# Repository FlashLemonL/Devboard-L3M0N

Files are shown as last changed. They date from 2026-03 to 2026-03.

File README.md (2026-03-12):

# Devboard-L3M0N
My attempt at making a devboard using the tutorial for when i want to start making IoT projects.

# 3D Model of PCB
Front 
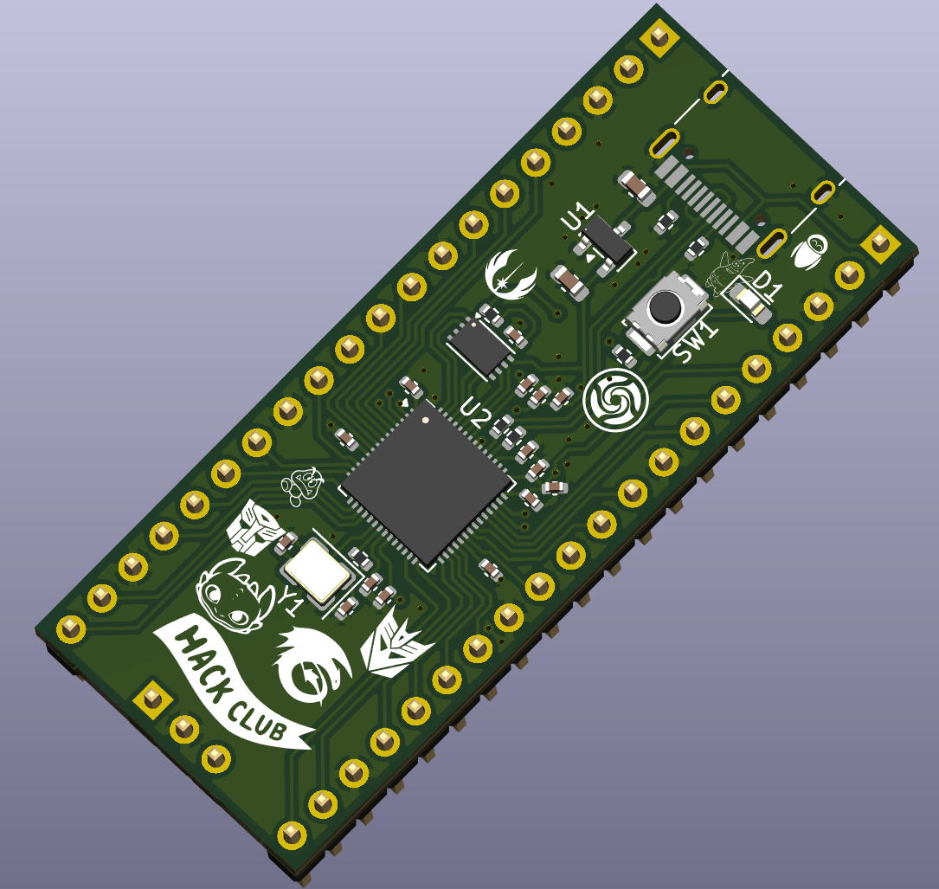
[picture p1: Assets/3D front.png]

Back
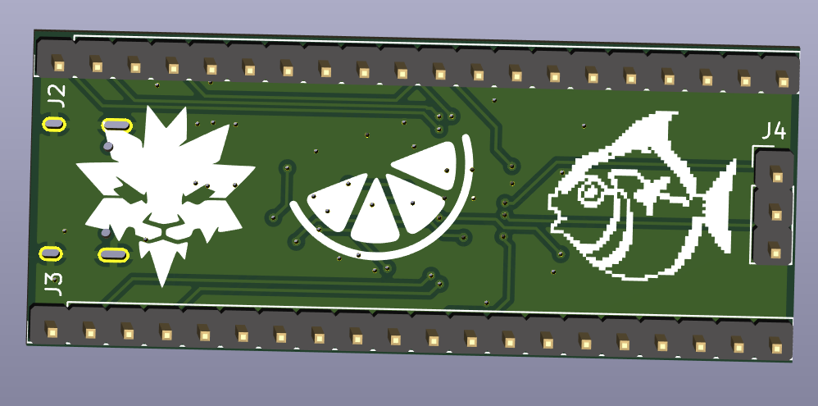
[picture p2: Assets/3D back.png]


# BOM
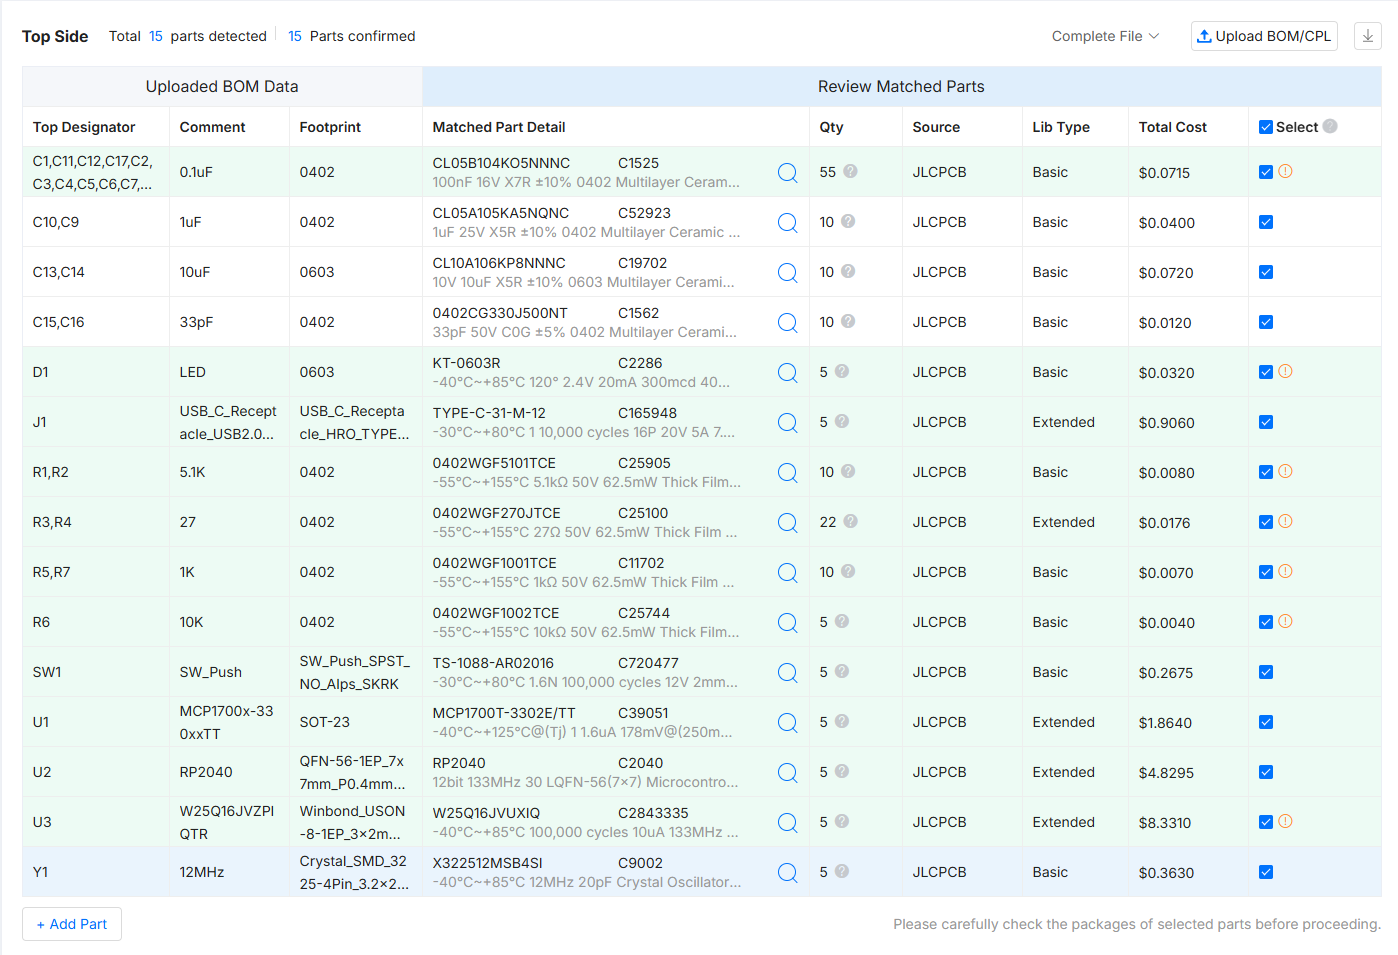
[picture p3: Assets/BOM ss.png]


# Parts Position
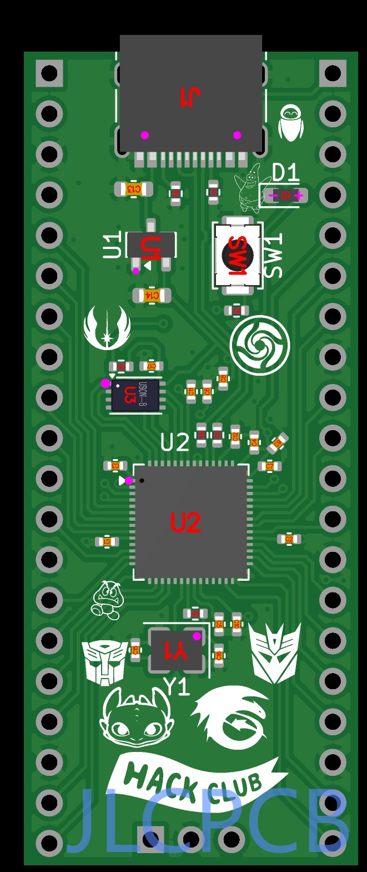
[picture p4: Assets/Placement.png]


# PCB
Schematic            |  PCB         |
:-------------------------:|:-------------------------:|
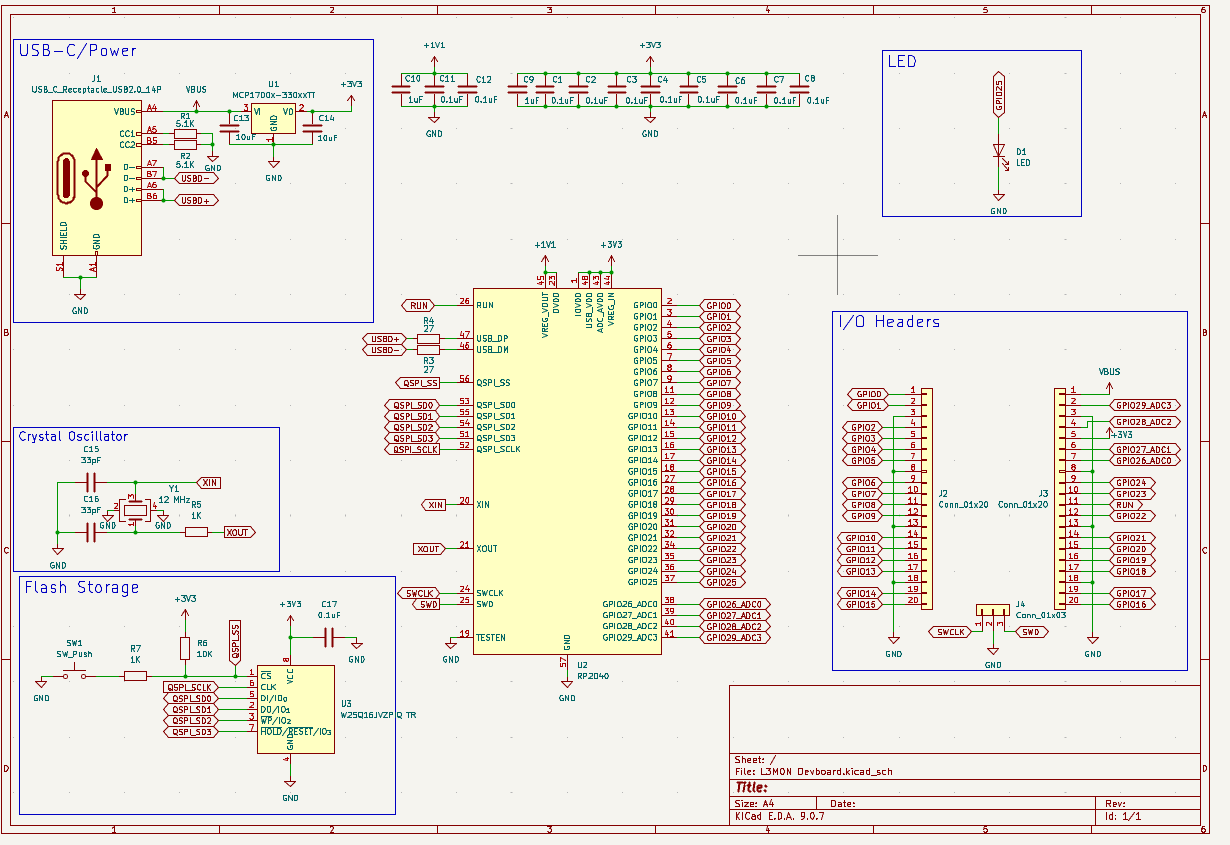
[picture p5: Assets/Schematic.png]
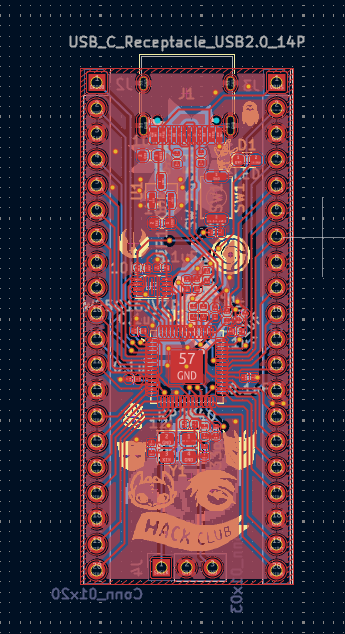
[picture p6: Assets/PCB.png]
    |    |

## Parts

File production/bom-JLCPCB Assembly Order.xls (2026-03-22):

JLCPCB BOM Tool - BOM Matching
BOM name：bom-JLCPCB Assembly Order.xlsx |  |  | Download Time：2026-03-22 16:55:20 |  |  |  | * Our matching results are updated in real-time, but stock and prices may change. If it's been over 24 hours, please re-match before placing your order.
PCB Assembled Qty：5 |  |  | Est. Total Price：16.8251
Your BOM |  |  |  |  | Matched Parts |  |  |  |  |  |  | Order Information
Top Designator | Bottom Designator | Comment | Footprint | JLCPCB Part # | Matches | Part # | Manufacturer | Footprint | Description | Category | Warning | JLCPCB Part # | Product link | Lib Type | Qty | Source | Total Price ($)
C1,C11,C12,C17,C2,C3,C4,C5,C6,C7,C8 |  | 0.1uF | 0402 |  | Select by Customer | CL05B104KO5NNNC | Samsung Electro-Mechanics | 0402 | 100nF 16V X7R ±10% 0402 Multilayer Ceramic Capacitors MLCC - SMD/SMT ROHS | Multilayer Ceramic Capacitors MLCC - SMD/SMT | 1.The comment (CL05B104KO5NNNC) of this part does not match the one (0.1uF) provided in your BOM. Please confirm; | C1525 | https://jlcpcb.com/partdetail/1877-CL05B104KO5NNNC/C1525 | Basic | 55 | 55 JLCPCB | 0.0715
C10,C9 |  | 1uF | 0402 |  | Select by System | CL05A105KA5NQNC | Samsung Electro-Mechanics | 0402 | 1uF 25V X5R ±10% 0402 Multilayer Ceramic Capacitors MLCC - SMD/SMT ROHS | Multilayer Ceramic Capacitors MLCC - SMD/SMT |  | C52923 | https://jlcpcb.com/partdetail/53938-CL05A105KA5NQNC/C52923 | Basic | 10 | 10 JLCPCB | 0.04
C13,C14 |  | 10uF | 0603 |  | Select by System | CL10A106KP8NNNC | Samsung Electro-Mechanics | 0603 | 10V 10uF X5R ±10% 0603 Multilayer Ceramic Capacitors MLCC - SMD/SMT ROHS | Multilayer Ceramic Capacitors MLCC - SMD/SMT |  | C19702 | https://jlcpcb.com/partdetail/20411-CL10A106KP8NNNC/C19702 | Basic | 10 | 10 JLCPCB | 0.072
C15,C16 |  | 33pF | 0402 |  | Select by System | 0402CG330J500NT | FH (Guangdong Fenghua Advanced Tech) | 0402 | 33pF 50V C0G ±5% 0402 Multilayer Ceramic Capacitors MLCC - SMD/SMT ROHS | Multilayer Ceramic Capacitors MLCC - SMD/SMT |  | C1562 | https://jlcpcb.com/partdetail/1914-0402CG330J500NT/C1562 | Basic | 10 | 10 JLCPCB | 0.012
D1 |  | LED | 0603 |  | Select by Customer | KT-0603R | Hubei KENTO Elec | 0603 | -40℃~+85℃ 120° 2.4V 20mA 300mcd 40mW 615nm~630nm 645nm Discrete Diode Red Water Clear 0603 LED Indication - Discrete ROHS | LED Indication - Discrete | 1.The comment (KT-0603R) of this part does not match the one (LED) provided in your BOM. Please confirm; | C2286 | https://jlcpcb.com/partdetail/Hubei_KENTOElec-KT0603R/C2286 | Basic | 5 | 5 JLCPCB | 0.032
J1 |  | USB_C_Receptacle_USB2.0_14P | USB_C_Receptacle_HRO_TYPE-C-31-M-12 |  | Select by Customer | TYPE-C-31-M-12 | Korean Hroparts Elec | SMD | -30℃~+80℃ 1 10,000 cycles 16P 20V 5A 7.35mm Female Surface Mount, Right Angle Type-C SMD USB Connectors ROHS | USB Connectors |  | C165948 | https://jlcpcb.com/partdetail/Korean_HropartsElec-TYPE_C_31_M12/C165948 | Extended | 5 | 5 JLCPCB | 0.906
R1,R2 |  | 5.1K | 0402 |  | Select by Customer | 0402WGF5101TCE | UNI-ROYAL(Uniroyal Elec) | 0402 | -55℃~+155℃ 5.1kΩ 50V 62.5mW Thick Film Resistor ±1% ±100ppm/℃ 0402 Chip Resistor - Surface Mount ROHS | Chip Resistor - Surface Mount | 1.The comment (0402WGF5101TCE) of this part does not match the one (5.1K) provided in your BOM. Please confirm; | C25905 | https://jlcpcb.com/partdetail/26648-0402WGF5101TCE/C25905 | Basic | 10 | 10 JLCPCB | 0.008
R3,R4 |  | 27 | 0402 |  | Select by Customer | 0402WGF270JTCE | UNI-ROYAL(Uniroyal Elec) | 0402 | -55℃~+155℃ 27Ω 50V 62.5mW Thick Film Resistor ±1% ±100ppm/℃ 0402 Chip Resistor - Surface Mount ROHS | Chip Resistor - Surface Mount | 1.The comment (0402WGF270JTCE) of this part does not match the one (27) provided in your BOM. Please confirm; | C25100 | https://jlcpcb.com/partdetail/25843-0402WGF270JTCE/C25100 | Extended | 22 | 22 JLCPCB | 0.0176
R5,R7 |  | 1K | 0402 |  | Select by Customer | 0402WGF1001TCE | UNI-ROYAL(Uniroyal Elec) | 0402 | -55℃~+155℃ 1kΩ 50V 62.5mW Thick Film Resistor ±1% ±100ppm/℃ 0402 Chip Resistor - Surface Mount ROHS | Chip Resistor - Surface Mount | 1.The comment (0402WGF1001TCE) of this part does not match the one (1K) provided in your BOM. Please confirm; | C11702 | https://jlcpcb.com/partdetail/12256-0402WGF1001TCE/C11702 | Basic | 10 | 10 JLCPCB | 0.007
R6 |  | 10K | 0402 |  | Select by Customer | 0402WGF1002TCE | UNI-ROYAL(Uniroyal Elec) | 0402 | -55℃~+155℃ 10kΩ 50V 62.5mW Thick Film Resistor ±1% ±100ppm/℃ 0402 Chip Resistor - Surface Mount ROHS | Chip Resistor - Surface Mount | 1.The comment (0402WGF1002TCE) of this part does not match the one (10K) provided in your BOM. Please confirm; | C25744 | https://jlcpcb.com/partdetail/26487-0402WGF1002TCE/C25744 | Basic | 5 | 5 JLCPCB | 0.004
SW1 |  | SW_Push | SW_Push_SPST_NO_Alps_SKRK |  | Select by Customer | TS-1088-AR02016 | XUNPU | SMD,4x3mm | -30℃~+80℃ 1.6N 100,000 cycles 12V 2mm 3mm 4mm 50mA Black Round Button SMD(SMT) Tab SPST Surface Mount,Vertical Without Bracket SMD,4x3mm Tactile Switches ROHS | Tactile Switches |  | C720477 | https://jlcpcb.com/partdetail/XUNPU-TS_1088AR02016/C720477 | Basic | 5 | 5 JLCPCB | 0.2675
U1 |  | MCP1700x-330xxTT | SOT-23 |  | Select by Customer | MCP1700T-3302E/TT | Microchip Tech | SOT-23 | -40℃~+125℃@(Tj) 1 1.6uA 178mV@(250mA) 250mA 3.3V 44dB@(100Hz) 6V Fixed Over Temperature Protection、Short Circuit Protection Positive SOT-23 Voltage Regulators - Linear, Low Drop Out (LDO) Regulators ROHS | Voltage Regulators - Linear, Low Drop Out (LDO) Regulators |  | C39051 | https://jlcpcb.com/partdetail/MicrochipTech-MCP1700T_3302ETT/C39051 | Extended | 5 | 5 JLCPCB | 1.864
U2 |  | RP2040 | QFN-56-1EP_7x7mm_P0.4mm_EP3.2x3.2mm |  | Select by Customer | RP2040 | Raspberry Pi | LQFN-56(7x7) | 12bit 133MHz 30 LQFN-56(7x7) Microcontrollers (MCU/MPU/SOC) ROHS | Microcontrollers (MCU/MPU/SOC) |  | C2040 | https://jlcpcb.com/partdetail/RaspberryPi-RP2040/C2040 | Extended | 5 | 5 JLCPCB | 4.8295
U3 |  | W25Q16JVZPIQTR | Winbond_USON-8-1EP_3x2mm_P0.5mm_EP0.2x1.6mm |  | Select by Customer | W25Q16JVUXIQ | Winbond Elec | USON-8-EP(2x3) | -40℃~+85℃ 100,000 cycles 10uA 133MHz 16Mbit 2.7V~3.6V 20 Years 3ms SPI USON-8-EP(2x3) NOR FLASH ROHS | NOR FLASH | 1.The comment (W25Q16JVUXIQ) of this part does not match the one (W25Q16JVZPIQTR) provided in your BOM. Please confirm; | C2843335 | https://jlcpcb.com/partdetail/WinbondElec-W25Q16JVUXIQ/C2843335 | Extended | 5 | 5 JLCPCB | 8.331
Y1 |  | 12MHz | Crystal_SMD_3225-4Pin_3.2x2.5mm |  | Select by Customer | X322512MSB4SI | YXC Crystal Oscillators | SMD3225-4P | -40℃~+85℃ 12MHz 20pF Crystal Oscillator ±10ppm ±20ppm SMD3225-4P Crystals ROHS | Crystals |  | C9002 | https://jlcpcb.com/partdetail/YXC_CrystalOscillators-X322512MSB4SI/C9002 | Basic | 5 | 5 JLCPCB | 0.363

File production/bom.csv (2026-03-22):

Designator | Footprint | Quantity | Value | LCSC Part #
C1, C11, C12, C17, C2, C3, C4, C5, C6, C7, C8 | 0402 | 11 | 0.1uF
C10, C9 | 0402 | 2 | 1uF
C13, C14 | 0603 | 2 | 10uF
C15, C16 | 0402 | 2 | 33pF
D1 | 0603 | 1 | LED
J1 | USB_C_Receptacle_HRO_TYPE-C-31-M-12 | 1 | USB_C_Receptacle_USB2.0_14P
J2, J3 | PinHeader_1x20_P2.54mm_Vertical | 2 | Conn_01x20
J4 | PinHeader_1x03_P2.54mm_Vertical | 1 | Conn_01x03
R1, R2 | 0402 | 2 | 5.1K
R3, R4 | 0402 | 2 | 27
R5, R7 | 0402 | 2 | 1K
R6 | 0402 | 1 | 10K
SW1 | SW_Push_SPST_NO_Alps_SKRK | 1 | SW_Push
U1 | SOT-23 | 1 | MCP1700x-330xxTT
U2 | QFN-56-1EP_7x7mm_P0.4mm_EP3.2x3.2mm | 1 | RP2040
U3 | Winbond_USON-8-1EP_3x2mm_P0.5mm_EP0.2x1.6mm | 1 | W25Q16JVZPIQ TR
Y1 | Crystal_SMD_3225-4Pin_3.2x2.5mm | 1 | 12 MHz

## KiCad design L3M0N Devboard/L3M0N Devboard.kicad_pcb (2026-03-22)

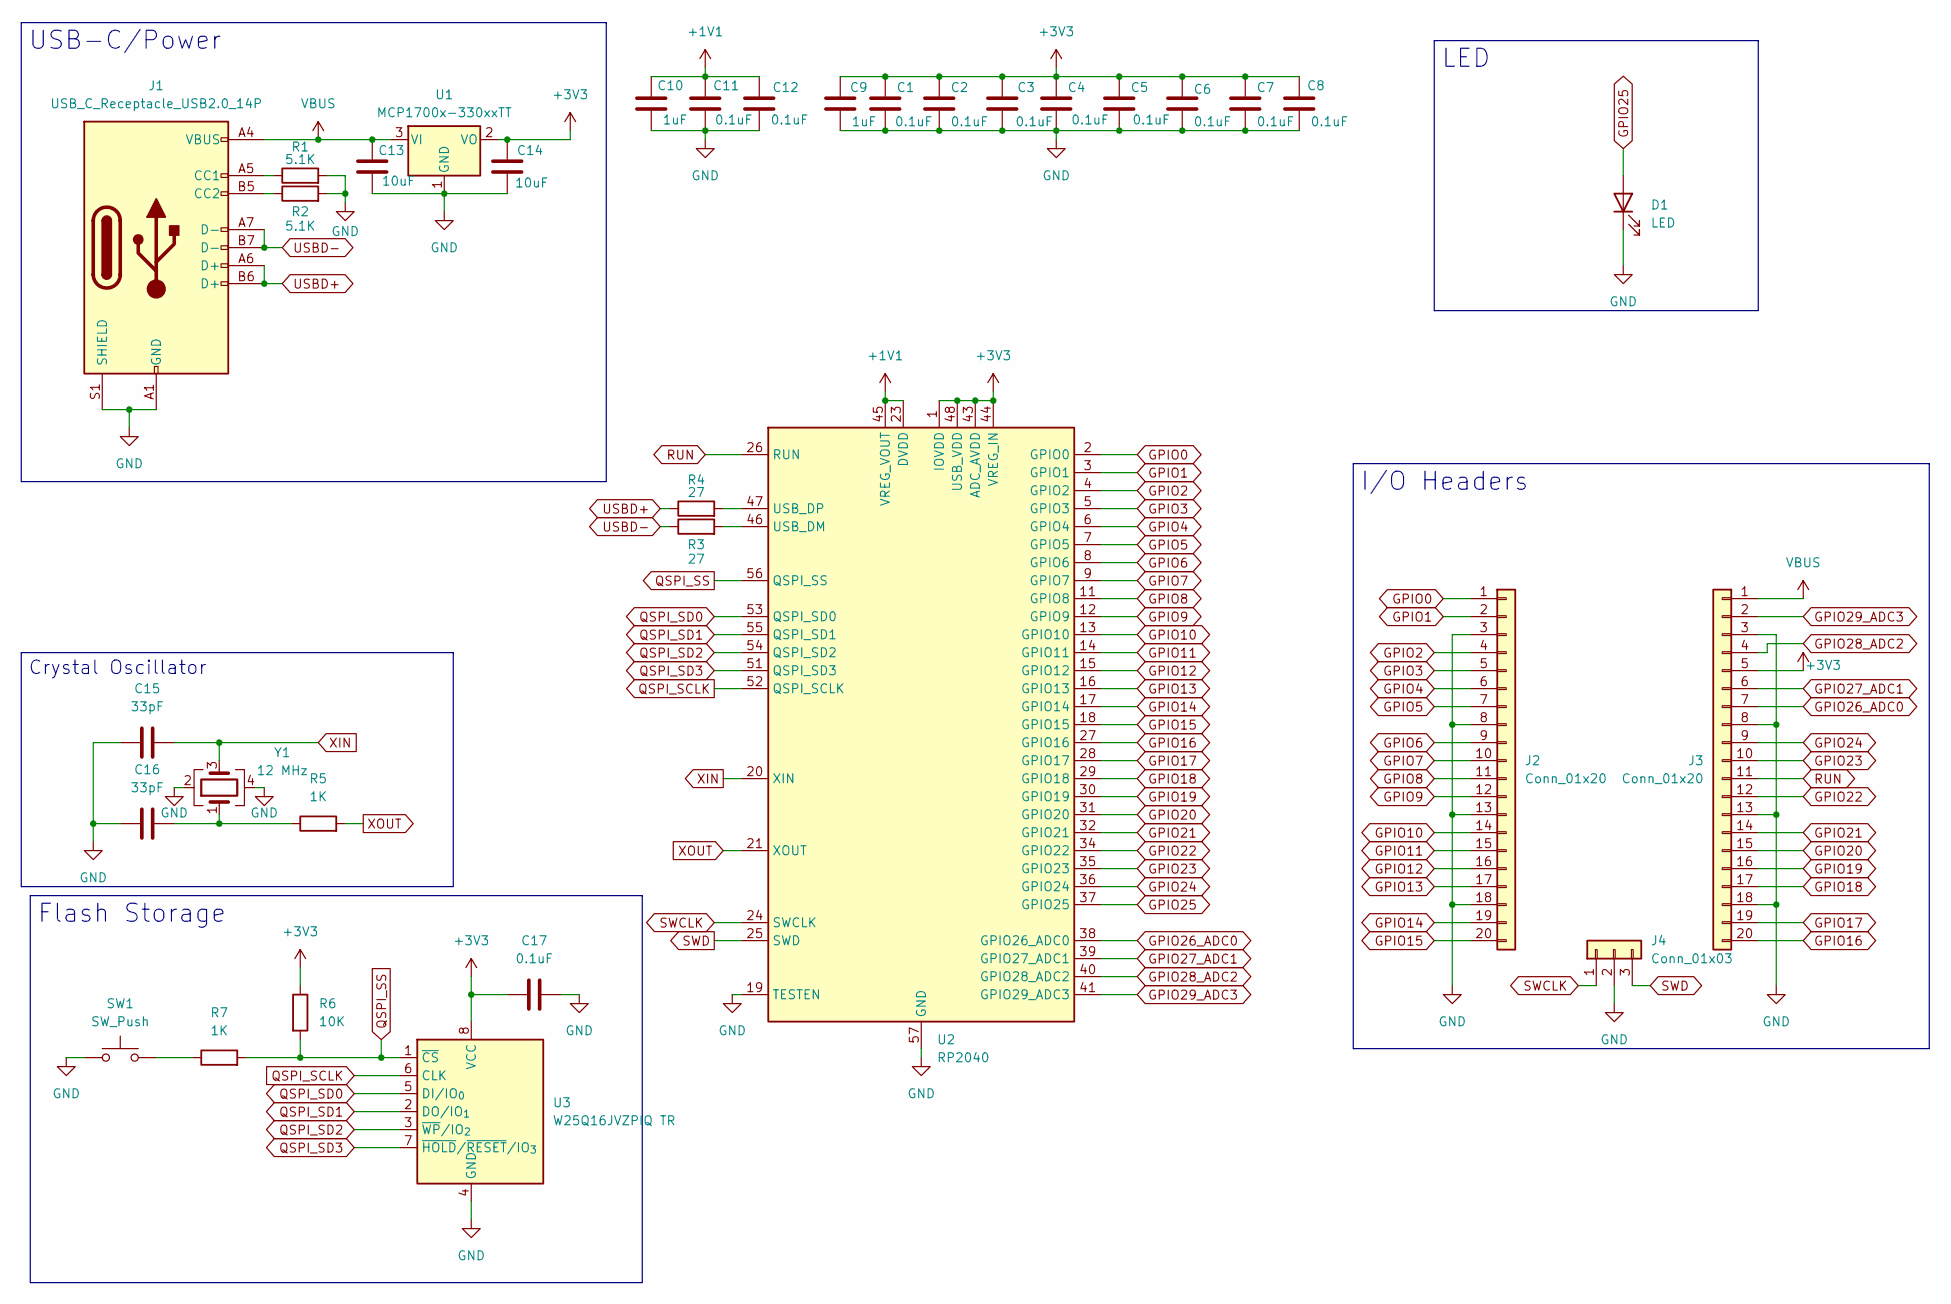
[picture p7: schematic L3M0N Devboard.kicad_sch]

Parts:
C1, C2, C3, C4, C5, C6, C7, C8, C11, C12, C17: 0.1uF; C_0402_1005Metric
C9, C10: 1uF; C_0402_1005Metric
C13, C14: 10uF; C_0603_1608Metric
C15, C16: 33pF; C_0402_1005Metric
D1: LED; LED_0603_1608Metric_Pad1.05x0.95mm_HandSolder
J1: USB_C_Receptacle_USB2.0_14P; USB_C_Receptacle_HRO_TYPE-C-31-M-12
J2, J3: Conn_01x20; PinHeader_1x20_P2.54mm_Vertical
J4: Conn_01x03; PinHeader_1x03_P2.54mm_Vertical
R1, R2: 5.1K; R_0402_1005Metric
R3, R4: 27; R_0402_1005Metric
R5, R7: 1K; R_0402_1005Metric
R6: 10K; R_0402_1005Metric
SW1: SW_Push; SW_Push_SPST_NO_Alps_SKRK
U1: MCP1700x-330xxTT; SOT-23
U2: RP2040; QFN-56-1EP_7x7mm_P0.4mm_EP3.2x3.2mm
U3: W25Q16JVZPIQ TR; Winbond_USON-8-1EP_3x2mm_P0.5mm_EP0.2x1.6mm
Y1: 12 MHz; Crystal_SMD_3225-4Pin_3.2x2.5mm

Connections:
+1V1: C10.1, C11.1, C12.1, U2.23 (DVDD), U2.45 (VREG_VOUT), U2.50 (DVDD)
+3V3: C1.1, C2.1, C3.1, C4.1, C5.1, C6.1, C7.1, C8.1, C9.1, C14.1, C17.1, J3.5, R6.1, U1.2 (VO), U2.1 (IOVDD), U2.10 (IOVDD), U2.22 (IOVDD), U2.33 (IOVDD), U2.42 (IOVDD), U2.43 (ADC_AVDD), U2.44 (VREG_IN), U2.48 (USB_VDD), U2.49 (IOVDD), U3.8 (VCC)
GND: C1.2, C2.2, C3.2, C4.2, C5.2, C6.2, C7.2, C8.2, C9.2, C10.2, C11.2, C12.2, C13.2, C14.2, C15.2, C16.1, C17.2, D1.1 (K), J1.A1 (GND), J1.A12 (GND), J1.B1 (GND), J1.B12 (GND), J1.S1 (SHIELD), J2.3, J2.8, J2.13, J2.18, J3.3, J3.8, J3.13, J3.18, J4.2, R1.2, R2.2, SW1.1, U1.1 (GND), U2.19 (TESTEN), U2.57 (GND), U3.4 (GND), Y1.2, Y1.4
GPIO0: J2.1, U2.2 (GPIO0)
GPIO1: J2.2, U2.3 (GPIO1)
GPIO2: J2.4, U2.4 (GPIO2)
GPIO3: J2.5, U2.5 (GPIO3)
GPIO4: J2.6, U2.6 (GPIO4)
GPIO5: J2.7, U2.7 (GPIO5)
GPIO6: J2.9, U2.8 (GPIO6)
GPIO7: J2.10, U2.9 (GPIO7)
GPIO8: J2.11, U2.11 (GPIO8)
GPIO9: J2.12, U2.12 (GPIO9)
GPIO10: J2.14, U2.13 (GPIO10)
GPIO11: J2.15, U2.14 (GPIO11)
GPIO12: J2.16, U2.15 (GPIO12)
GPIO13: J2.17, U2.16 (GPIO13)
GPIO14: J2.19, U2.17 (GPIO14)
GPIO15: J2.20, U2.18 (GPIO15)
GPIO16: J3.20, U2.27 (GPIO16)
GPIO17: J3.19, U2.28 (GPIO17)
GPIO18: J3.17, U2.29 (GPIO18)
GPIO19: J3.16, U2.30 (GPIO19)
GPIO20: J3.15, U2.31 (GPIO20)
GPIO21: J3.14, U2.32 (GPIO21)
GPIO22: J3.12, U2.34 (GPIO22)
GPIO23: J3.10, U2.35 (GPIO23)
GPIO24: J3.9, U2.36 (GPIO24)
GPIO25: D1.2 (A), U2.37 (GPIO25)
GPIO26_ADC0: J3.7, U2.38 (GPIO26_ADC0)
GPIO27_ADC1: J3.6, U2.39 (GPIO27_ADC1)
GPIO28_ADC2: J3.4, U2.40 (GPIO28_ADC2)
GPIO29_ADC3: J3.2, U2.41 (GPIO29_ADC3)
unnamed: C16.2, R5.1, Y1.1
unnamed: J1.A5 (CC1), R1.1
unnamed: J1.B5 (CC2), R2.1
unnamed: R7.1, SW1.2
unnamed: R3.2, U2.46 (USB_DM)
unnamed: R4.2, U2.47 (USB_DP)
QSPI_SCLK: U2.52 (QSPI_SCLK), U3.6 (CLK)
QSPI_SD0: U2.53 (QSPI_SD0), U3.5 (DI/IO_{0})
QSPI_SD1: U2.55 (QSPI_SD1), U3.2 (DO/IO_{1})
QSPI_SD2: U2.54 (QSPI_SD2), U3.3 (~WP/IO_{2})
QSPI_SD3: U2.51 (QSPI_SD3), U3.7 (~HOLD/~RESET/IO_{3})
QSPI_SS: R6.2, R7.2, U2.56 (QSPI_SS), U3.1 (~CS)
RUN: J3.11, U2.26 (RUN)
SWCLK: J4.1, U2.24 (SWCLK)
SWD: J4.3, U2.25 (SWD)
USBD+: J1.A6 (D+), J1.B6 (D+), R4.1
USBD-: J1.A7 (D-), J1.B7 (D-), R3.1
VBUS: C13.1, J1.A4 (VBUS), J1.A9 (VBUS), J1.B4 (VBUS), J1.B9 (VBUS), J3.1, U1.3 (VI)
XIN: C15.1, U2.20 (XIN), Y1.3
XOUT: R5.2, U2.21 (XOUT)

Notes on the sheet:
Flash Storage
USB-C/Power
I/O Headers
Crystal Oscillator
LED

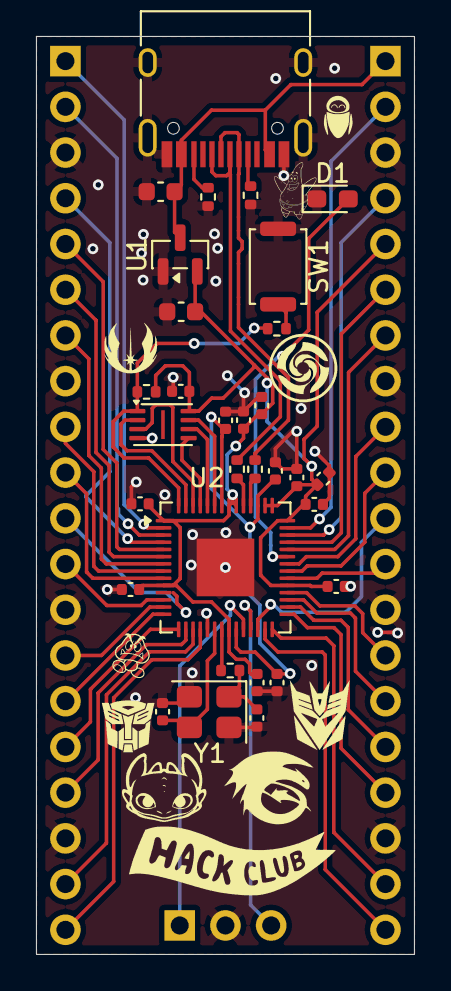
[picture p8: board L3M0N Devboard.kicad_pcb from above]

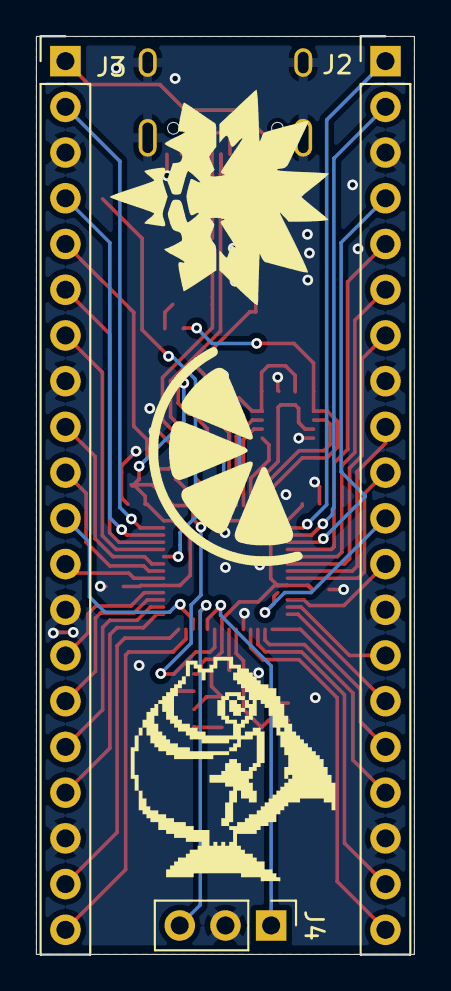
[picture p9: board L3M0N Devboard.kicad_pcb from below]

Board: 2 copper layers, 21.0 x 51.0 mm, 34 parts (3 on the bottom side), 53 nets.

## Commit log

2025-12-22 Added RP2040 to schematic and power decoupling
    [L3M0N Devboard.kicad_pcb, L3M0N Devboard.kicad_sch]
2025-12-22 Added USB C receptacle
    [L3M0N Devboard.kicad_sch]
2025-12-22 Added crystal oscilator
    [L3M0N Devboard.kicad_sch]
2026-03-06 Assigned footrprints
    [L3M0N Devboard.kicad_sch]
2026-03-06 Started positioning parts for pcb
    [L3M0N Devboard.kicad_pcb]
2026-03-09 started some of the wiring
    [L3M0N Devboard.kicad_pcb, L3M0N Devboard.kicad_sch]
2026-03-09 Wired up the left side of the devboard (Besides GND)
    [L3M0N Devboard.kicad_pcb]
2026-03-09 added left wires and ground fill
    [L3M0N Devboard.kicad_pcb]
2026-03-10 fixed ground fill and silkscreen and added things to silkscreen
    [L3M0N Devboard.kicad_pcb]
2026-03-11 made the gerber file
    [L3M0N Devboard-B_Cu.gbr, L3M0N Devboard-B_Mask.gbr, L3M0N Devboard-B_Paste.gbr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]
2026-03-12 Added Pictures for ReadMe
    [L3M0N Devboard-B_Cu.gbr, L3M0N Devboard-B_Mask.gbr, L3M0N Devboard-B_Paste.gbr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]
2026-03-22 Added LED and updated ReadMe
    [L3M0N Devboard-B_Cu.gbr, L3M0N Devboard-B_Mask.gbr, L3M0N Devboard-B_Paste.gbr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]
